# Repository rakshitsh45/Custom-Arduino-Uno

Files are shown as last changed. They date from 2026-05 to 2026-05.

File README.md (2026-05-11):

# Custom Arduino Uno PCB

A custom Arduino Uno compatible PCB designed using KiCad.

## Features
- ATmega328P-A microcontroller
- CH340G USB-to-Serial converter
- USB-A connector
- AMS1117 voltage regulator
- 16 MHz crystal oscillator
- ISP programming header
- Analog and digital headers

## Software Used
- KiCad

## Project Status
Completed PCB design with zero DRC errors and warnings.

## PCB Layout
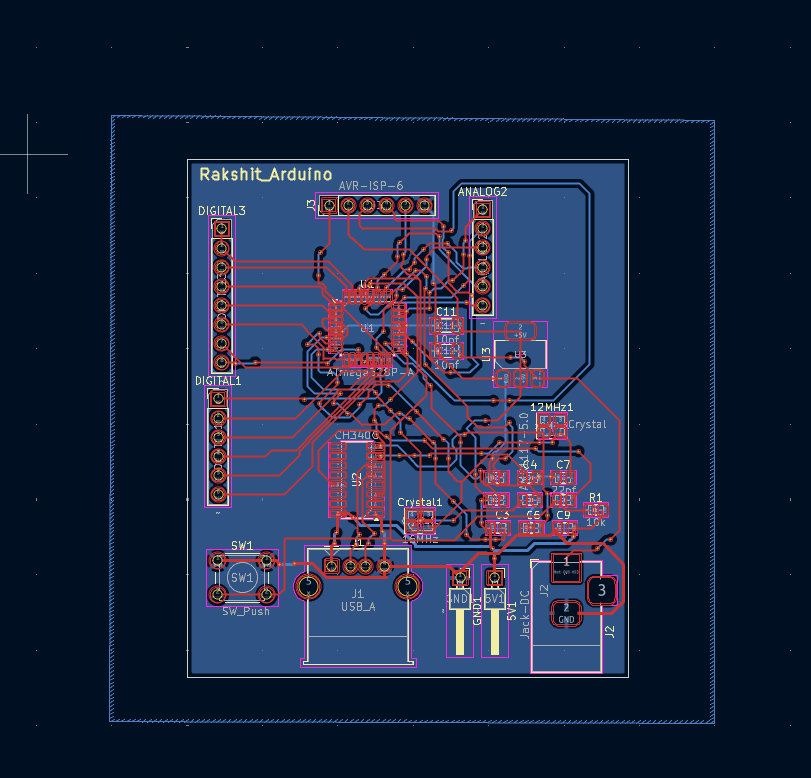
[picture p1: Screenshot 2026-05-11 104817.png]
PCB


## Schematic
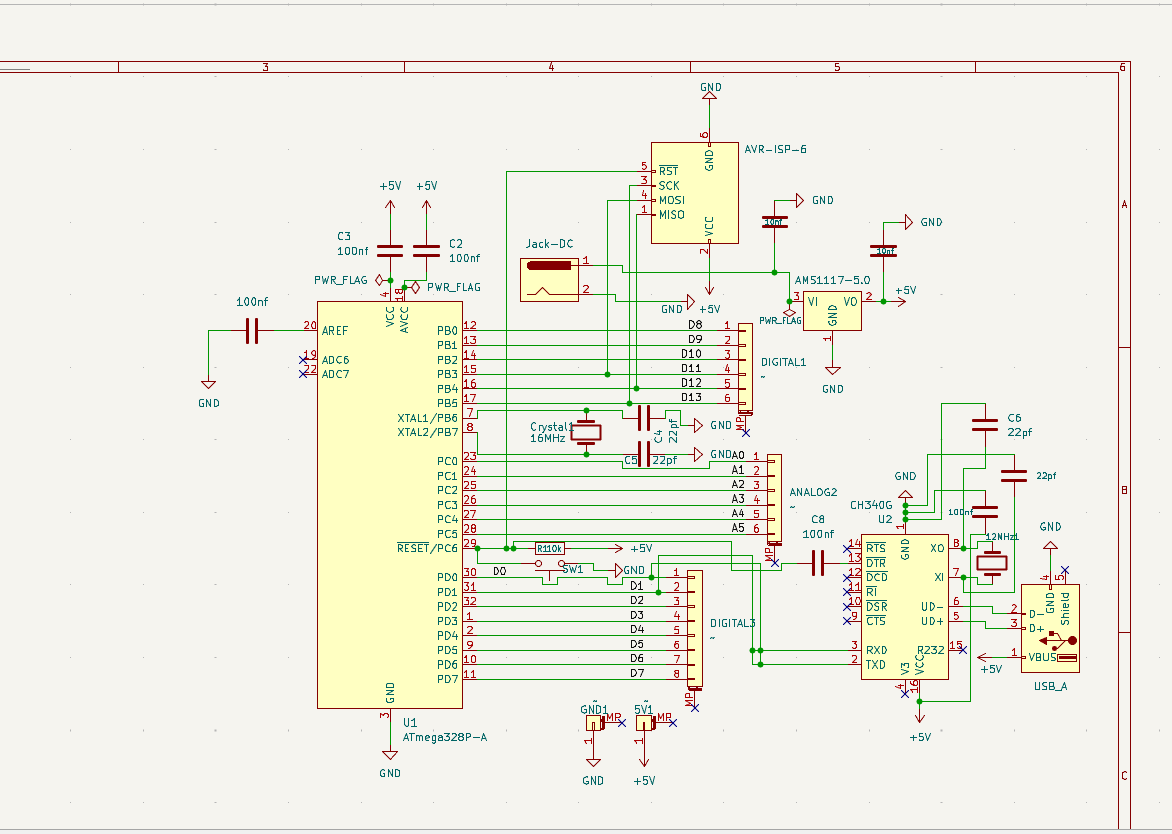
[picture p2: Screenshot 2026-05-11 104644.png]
Schematic


## 3D View
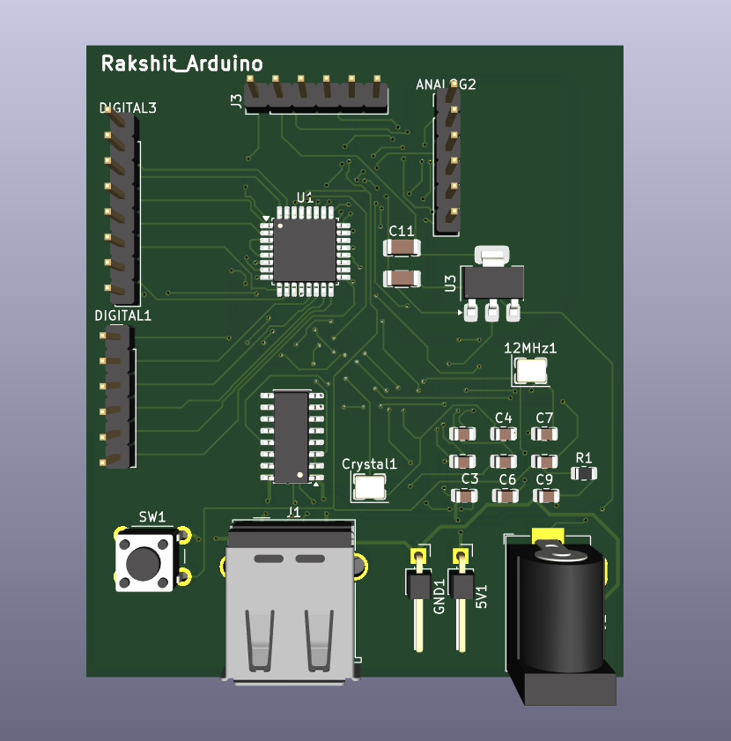
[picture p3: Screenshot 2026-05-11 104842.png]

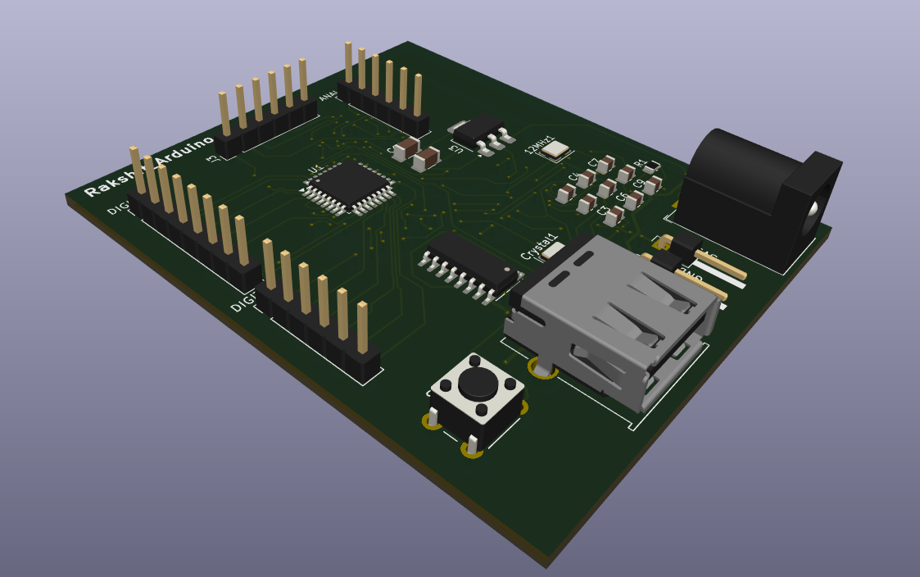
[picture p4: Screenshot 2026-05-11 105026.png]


## Author
Rakshit

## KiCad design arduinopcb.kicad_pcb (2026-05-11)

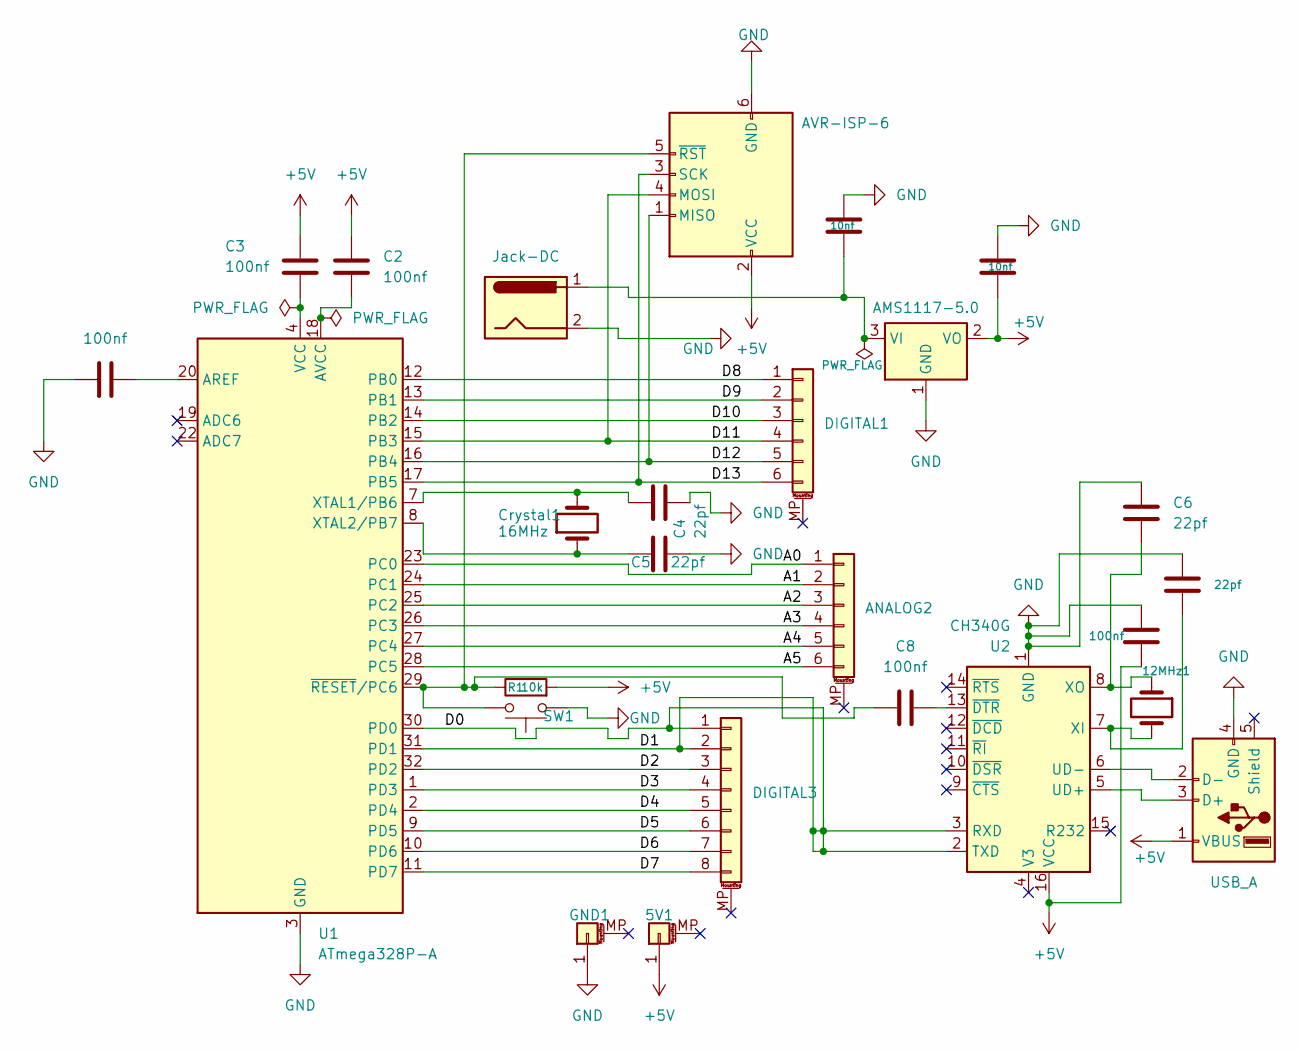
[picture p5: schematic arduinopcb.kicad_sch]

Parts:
5V1: PinHeader_1x01_P2.54mm_Horizontal
12MHz1: Crystal; Crystal_SMD_3225-4Pin_3.2x2.5mm
ANALOG2: PinHeader_1x06_P2.54mm_Vertical
C1, C2, C3, C8, C9: 100nf; C_0805_2012Metric
C4, C5, C6, C7: 22pf; C_0805_2012Metric
C11, C12: 10nf; C_1206_3216Metric
Crystal1: 16MHz; Crystal_SMD_3225-4Pin_3.2x2.5mm
DIGITAL1: PinHeader_1x06_P2.54mm_Vertical
DIGITAL3: PinHeader_1x08_P2.54mm_Vertical
GND1: PinHeader_1x01_P2.54mm_Horizontal
J1: USB_A; USB_A_Molex_67643_Horizontal
J2: Jack-DC; BarrelJack_Horizontal
J3: AVR-ISP-6; PinHeader_1x06_P2.54mm_Vertical
R1: 10k; R_0805_2012Metric
SW1: SW_Push; SW_PUSH_6mm
U1: ATmega328P-A; TQFP-32_7x7mm_P0.8mm
U2: CH340G; SOIC-16_3.9x9.9mm_P1.27mm
U3: AMS1117-5.0; SOT-223-3_TabPin2

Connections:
+5V: 5V1.1, C2.1, C3.1, C9.2, C11.2, J1.1 (VBUS), J3.2 (VCC), R1.2, U2.16 (VCC), U3.2 (VO)
/A0: ANALOG2.1, U1.23 (PC0)
/A1: ANALOG2.2, U1.24 (PC1)
/A2: ANALOG2.3, U1.25 (PC2)
/A3: ANALOG2.4, U1.26 (PC3)
/A4: ANALOG2.5, U1.27 (PC4)
/A5: ANALOG2.6, U1.28 (PC5)
/D0: DIGITAL3.1, DIGITAL3.2, U1.30 (PD0), U1.31 (PD1), U2.2 (TXD), U2.3 (RXD)
/D2: DIGITAL3.3, U1.32 (PD2)
/D3: DIGITAL3.4, U1.1 (PD3)
/D4: DIGITAL3.5, U1.2 (PD4)
/D5: DIGITAL3.6, U1.9 (PD5)
/D6: DIGITAL3.7, U1.10 (PD6)
/D7: DIGITAL3.8, U1.11 (PD7)
/D8: DIGITAL1.1, U1.12 (PB0)
/D9: DIGITAL1.2, U1.13 (PB1)
/D10: DIGITAL1.3, U1.14 (PB2)
/D11: DIGITAL1.4, J3.4 (MOSI), U1.15 (PB3)
/D12: DIGITAL1.5, J3.1 (MISO), U1.16 (PB4)
/D13: DIGITAL1.6, J3.3 (SCK), U1.17 (PB5)
GND: C1.1, C4.2, C5.2, C6.1, C7.1, C9.1, C11.1, C12.1, GND1.1, J1.4 (GND), J2.2, J3.6 (GND), SW1.1, U1.3 (GND), U1.5 (GND), U1.21 (GND), U2.1 (GND), U3.1 (GND)
unnamed: C3.2, U1.4 (VCC), U1.6 (VCC)
unnamed: J1.3 (D+), U2.5 (UD+)
unnamed: J1.2 (D-), U2.6 (UD-)
unnamed: C8.1, J3.5 (~RST), R1.1, SW1.2, U1.29 (~RESET/PC6)
unnamed: C1.2, U1.20 (AREF)
unnamed: C2.2, U1.18 (AVCC)
unnamed: C4.1, Crystal1.2, U1.7 (XTAL1/PB6)
unnamed: C5.1, Crystal1.1, U1.8 (XTAL2/PB7)
unnamed: 12MHz1.2, C7.2, U2.7 (XI)
unnamed: 12MHz1.1, C6.2, U2.8 (XO)
unnamed: C8.2, U2.13 (~DTR)
unnamed: C12.2, J2.1, U3.3 (VI)

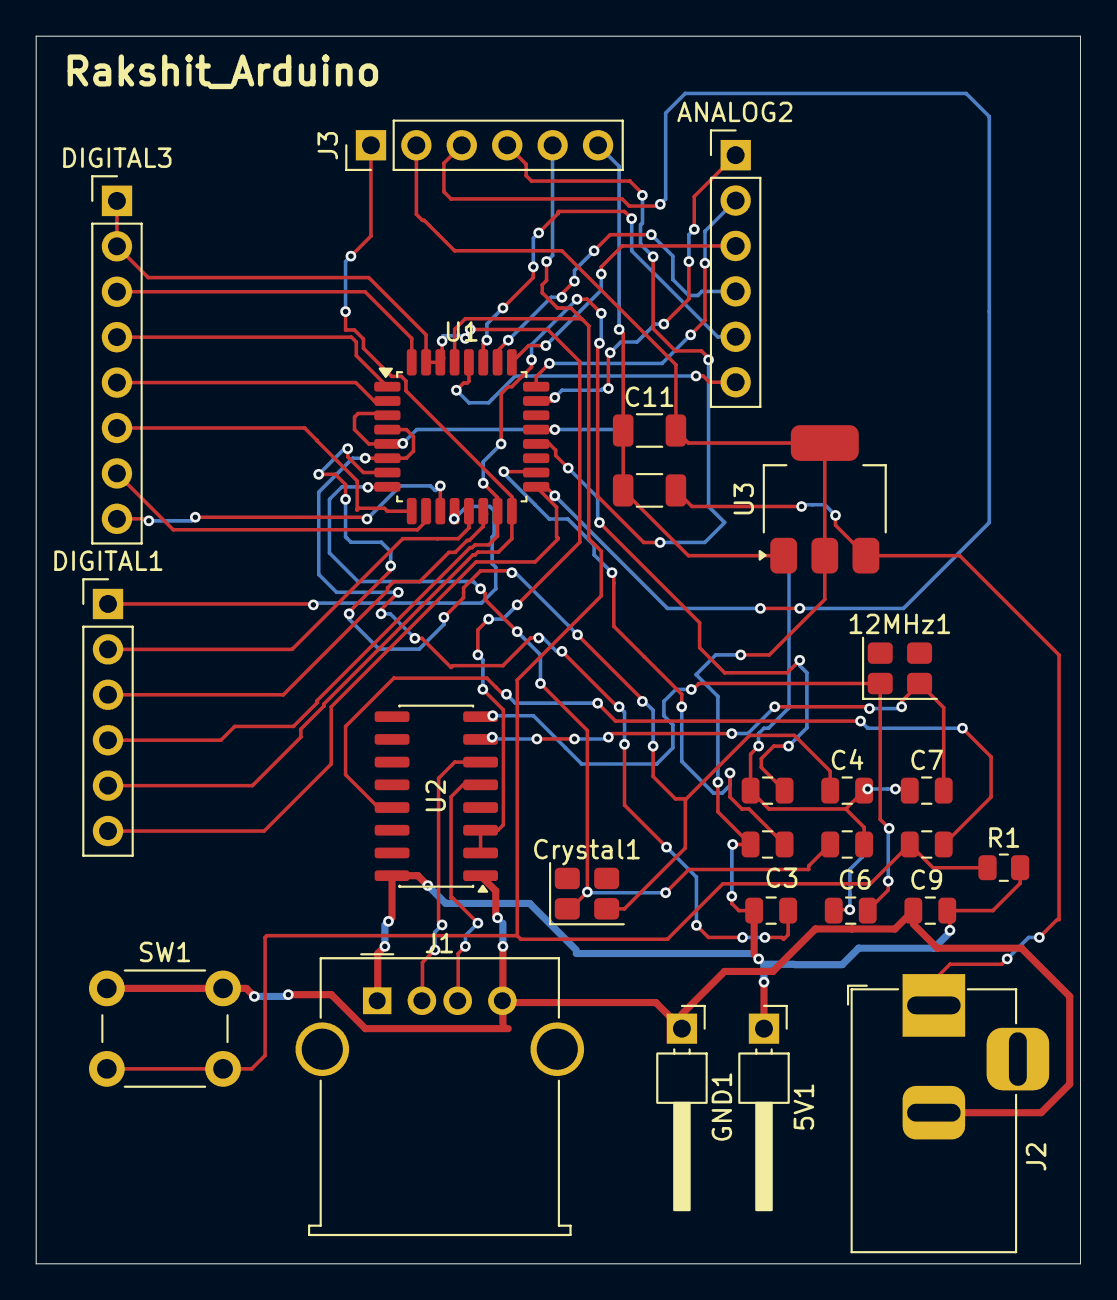
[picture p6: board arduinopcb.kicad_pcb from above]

Board: 2 copper layers, 58.4 x 68.7 mm, 26 parts (0 on the bottom side), 33 nets.

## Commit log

2026-05-11 Initial upload of Arduino Uno PCB project
    [arduinopcb.kicad_pcb, arduinopcb.kicad_sch]
2026-05-11 Added PCB and schematic images
